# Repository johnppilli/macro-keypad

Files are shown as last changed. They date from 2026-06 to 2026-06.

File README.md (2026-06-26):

# Macro Keypad — Custom USB Mechanical Keypad (KiCad)

A custom 9-key (3×3) USB-C mechanical macro keypad, designed from schematic to
fabrication in KiCad around an **RP2040** microcontroller. This is my own design —
schematic capture, component selection, PCB layout, and fabrication.

## The fabricated board

| Top | Bottom |
| --- | --- |
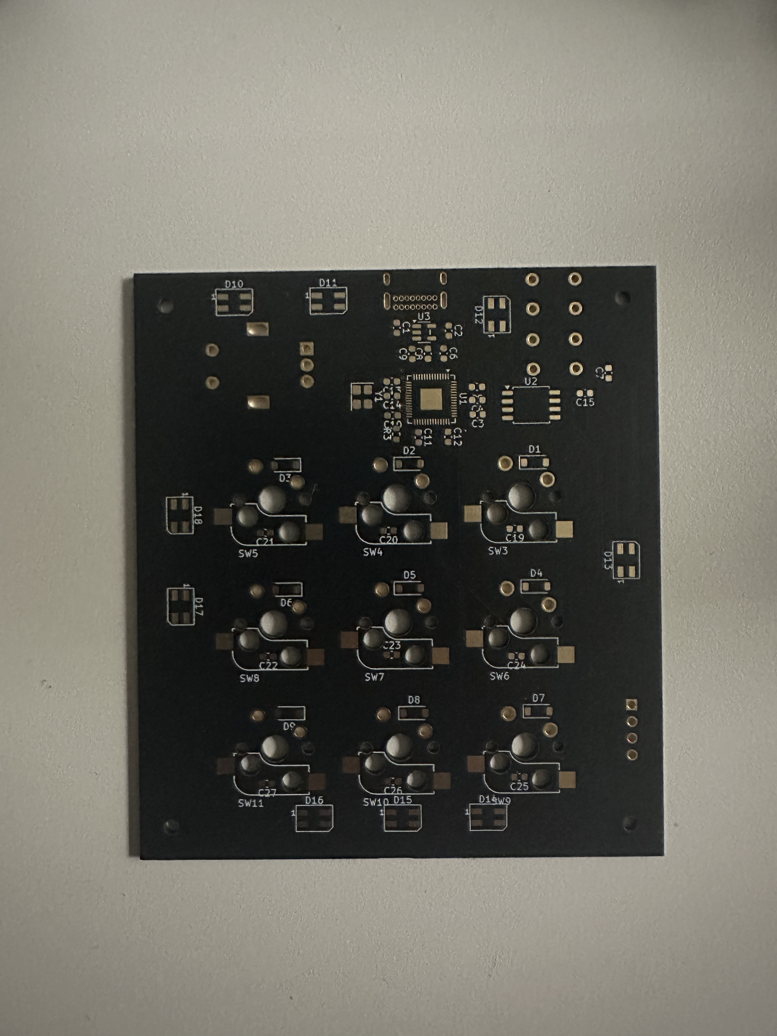
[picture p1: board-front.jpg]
Board top
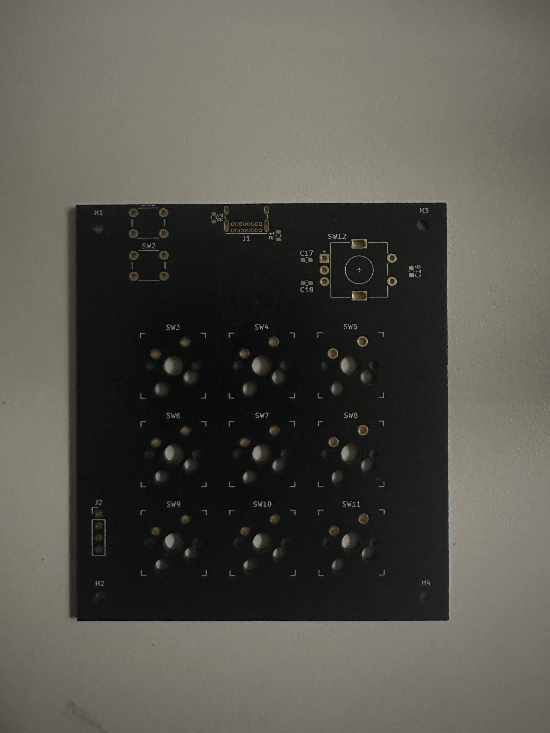
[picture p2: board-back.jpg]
Board bottom
|  |  |

*Bare 2-layer board from JLCPCB, prior to switch/component assembly.*

## Design highlights

- **RP2040** microcontroller with USB-C for both power and data
- **USBLC6** ESD protection on the USB data lines
- **3×3 matrix of 9 mechanical key switches**, each with a per-key diode for N-key
  rollover / anti-ghosting during matrix scanning
- Decoupling on each supply pin; crystal and supporting passives per the RP2040
  reference design
- **2-layer PCB**, board outline defined in Edge.Cuts, ERC/DRC clean
- Gerbers + drill files generated and **fabricated through JLCPCB**

## What's in this repo

- `macro-keypad.kicad_sch` / `.kicad_pcb` / `.kicad_pro` — the KiCad project
- `macro-keypad.pdf` — schematic PDF
- `gerbers/` — fabrication outputs
- `board-front.jpg` / `board-back.jpg` — photos of the fabricated board

## Status — in progress

Bare fabricated board is in hand. Currently:

- **Hand-soldering** the switches, per-key diodes, and supporting components onto the board
- **Writing the RP2040 firmware** — USB-HID keyboard with matrix scanning and debounce

Next up: bring-up and testing once assembly is complete.

## Tools

KiCad · JLCPCB

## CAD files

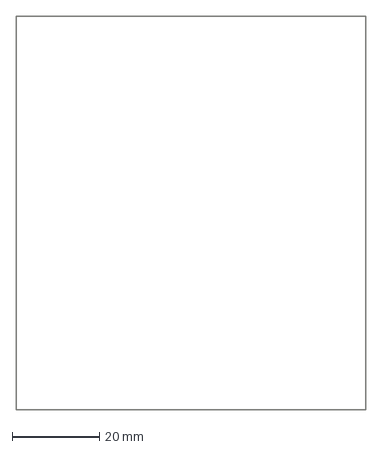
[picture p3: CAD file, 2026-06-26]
macro-keypad-Edge_Cuts.dxf
80.1 x 90.0 mm

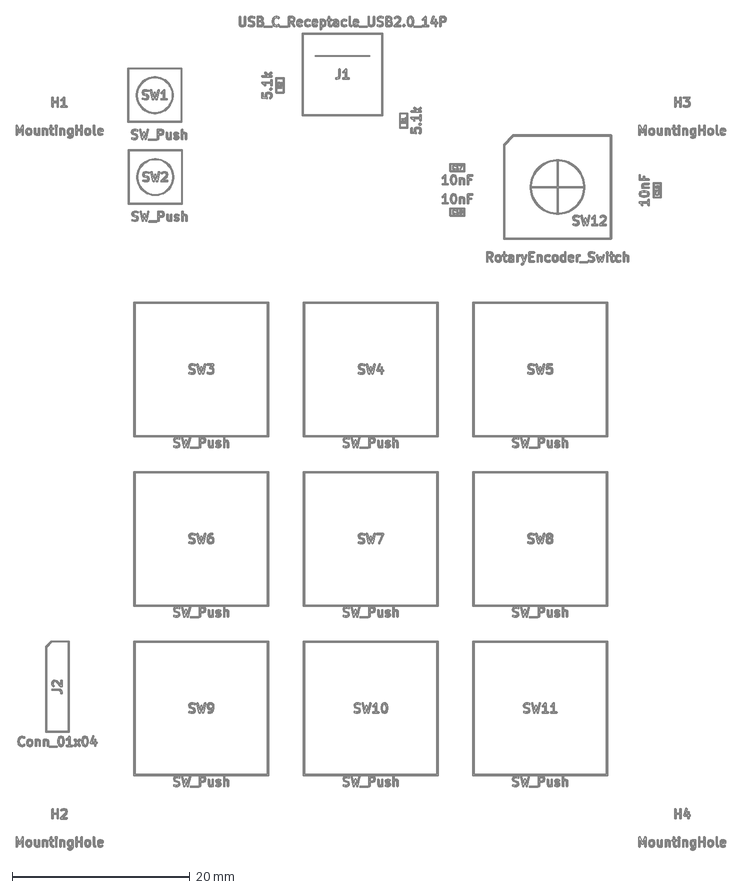
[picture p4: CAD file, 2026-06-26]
macro-keypad-F_Fab.dxf
79.8 x 93.7 mm

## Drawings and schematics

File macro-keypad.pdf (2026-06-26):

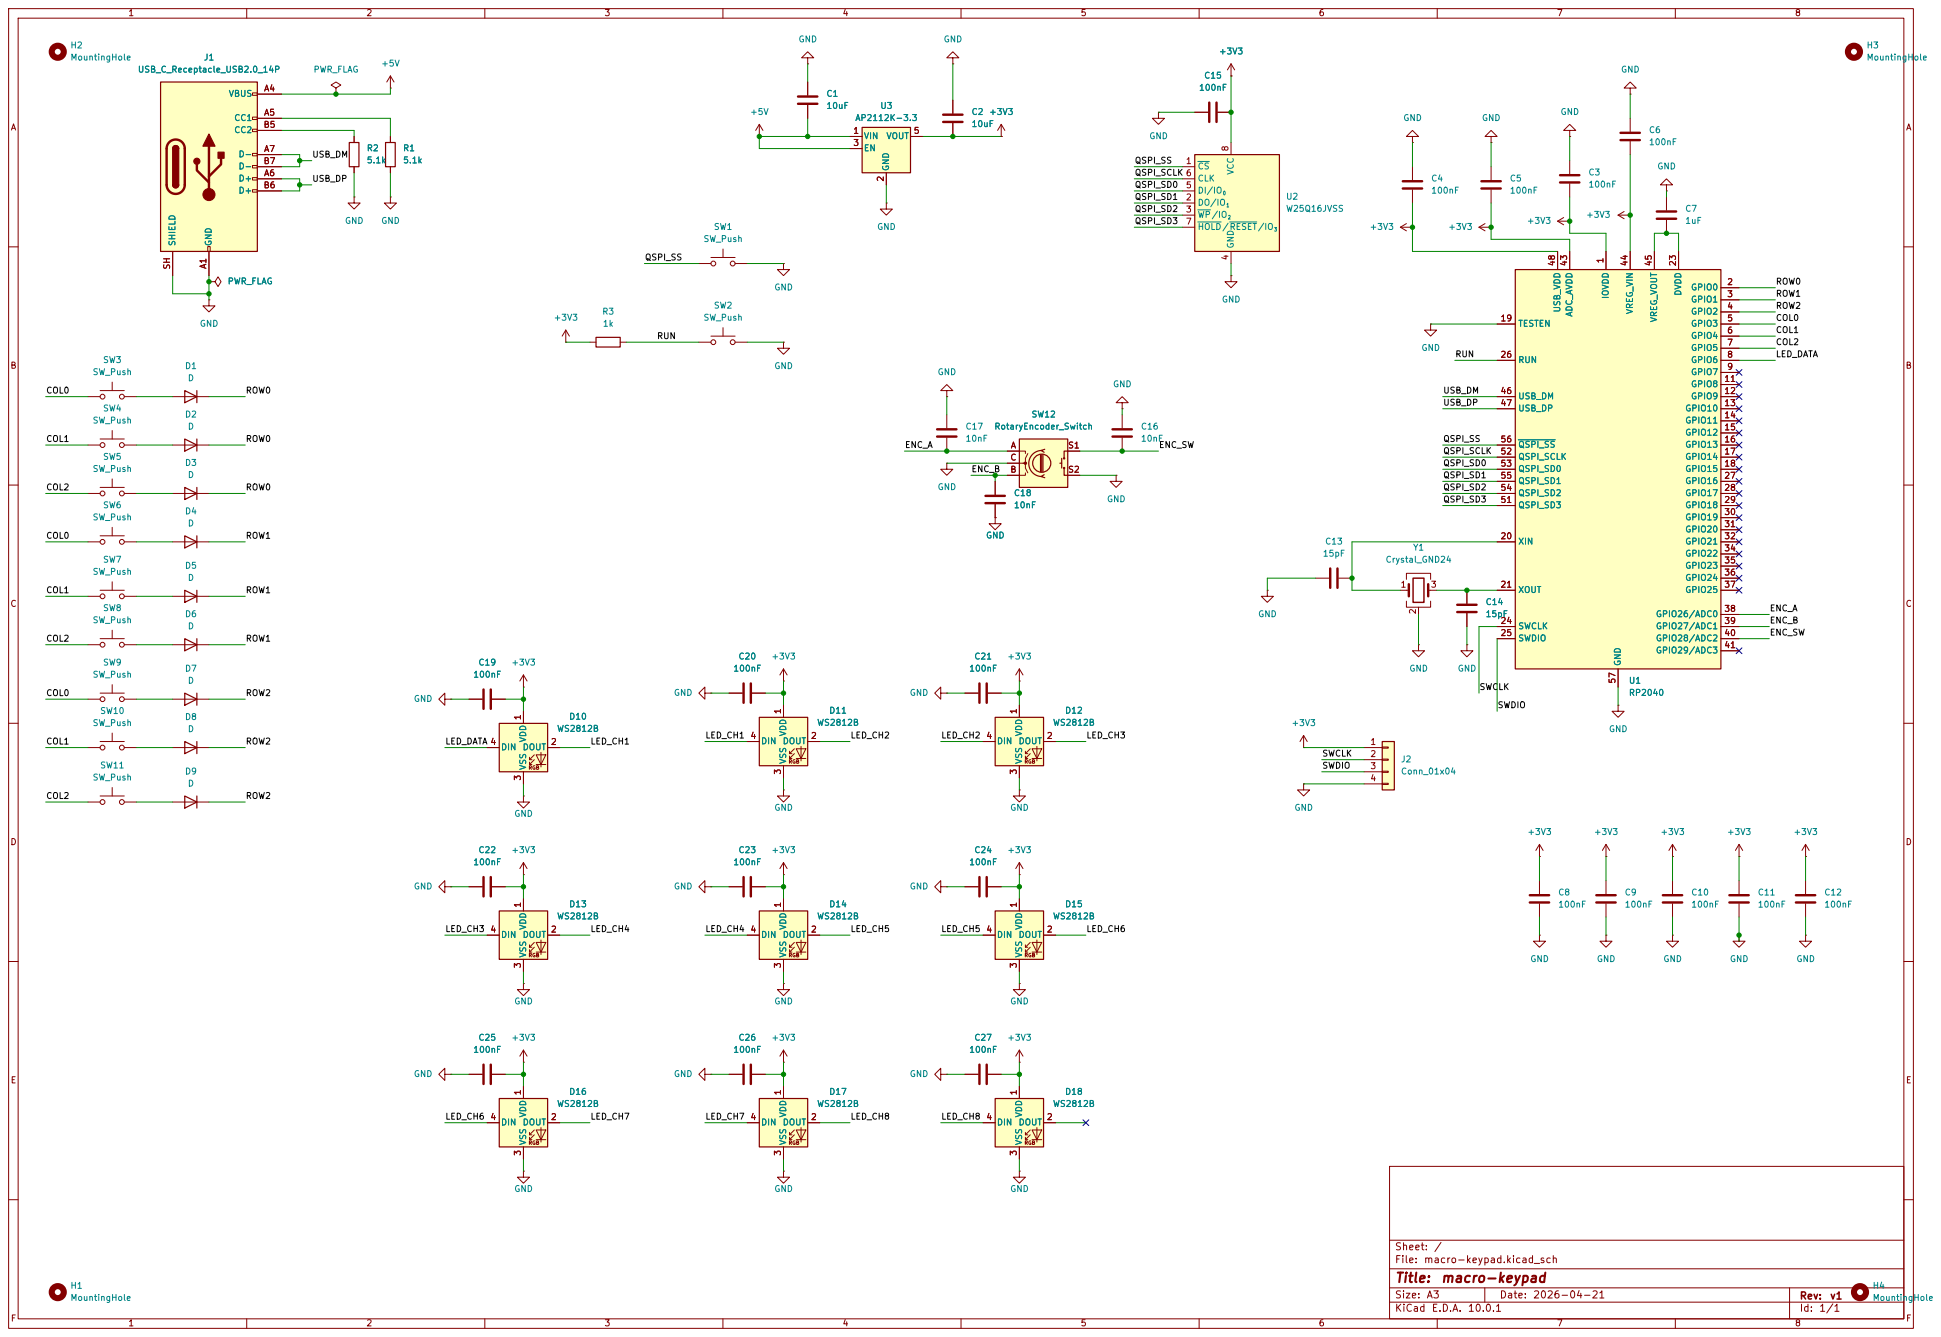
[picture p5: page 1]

4 DI/IO0 5 CLK 6 HOLD/RESET/IO3 7 VCC

Size: A3 | Rev: v1 | F Date: 2026-04-21
KiCad E.D.A. 10.0.1 | Id: 1/1

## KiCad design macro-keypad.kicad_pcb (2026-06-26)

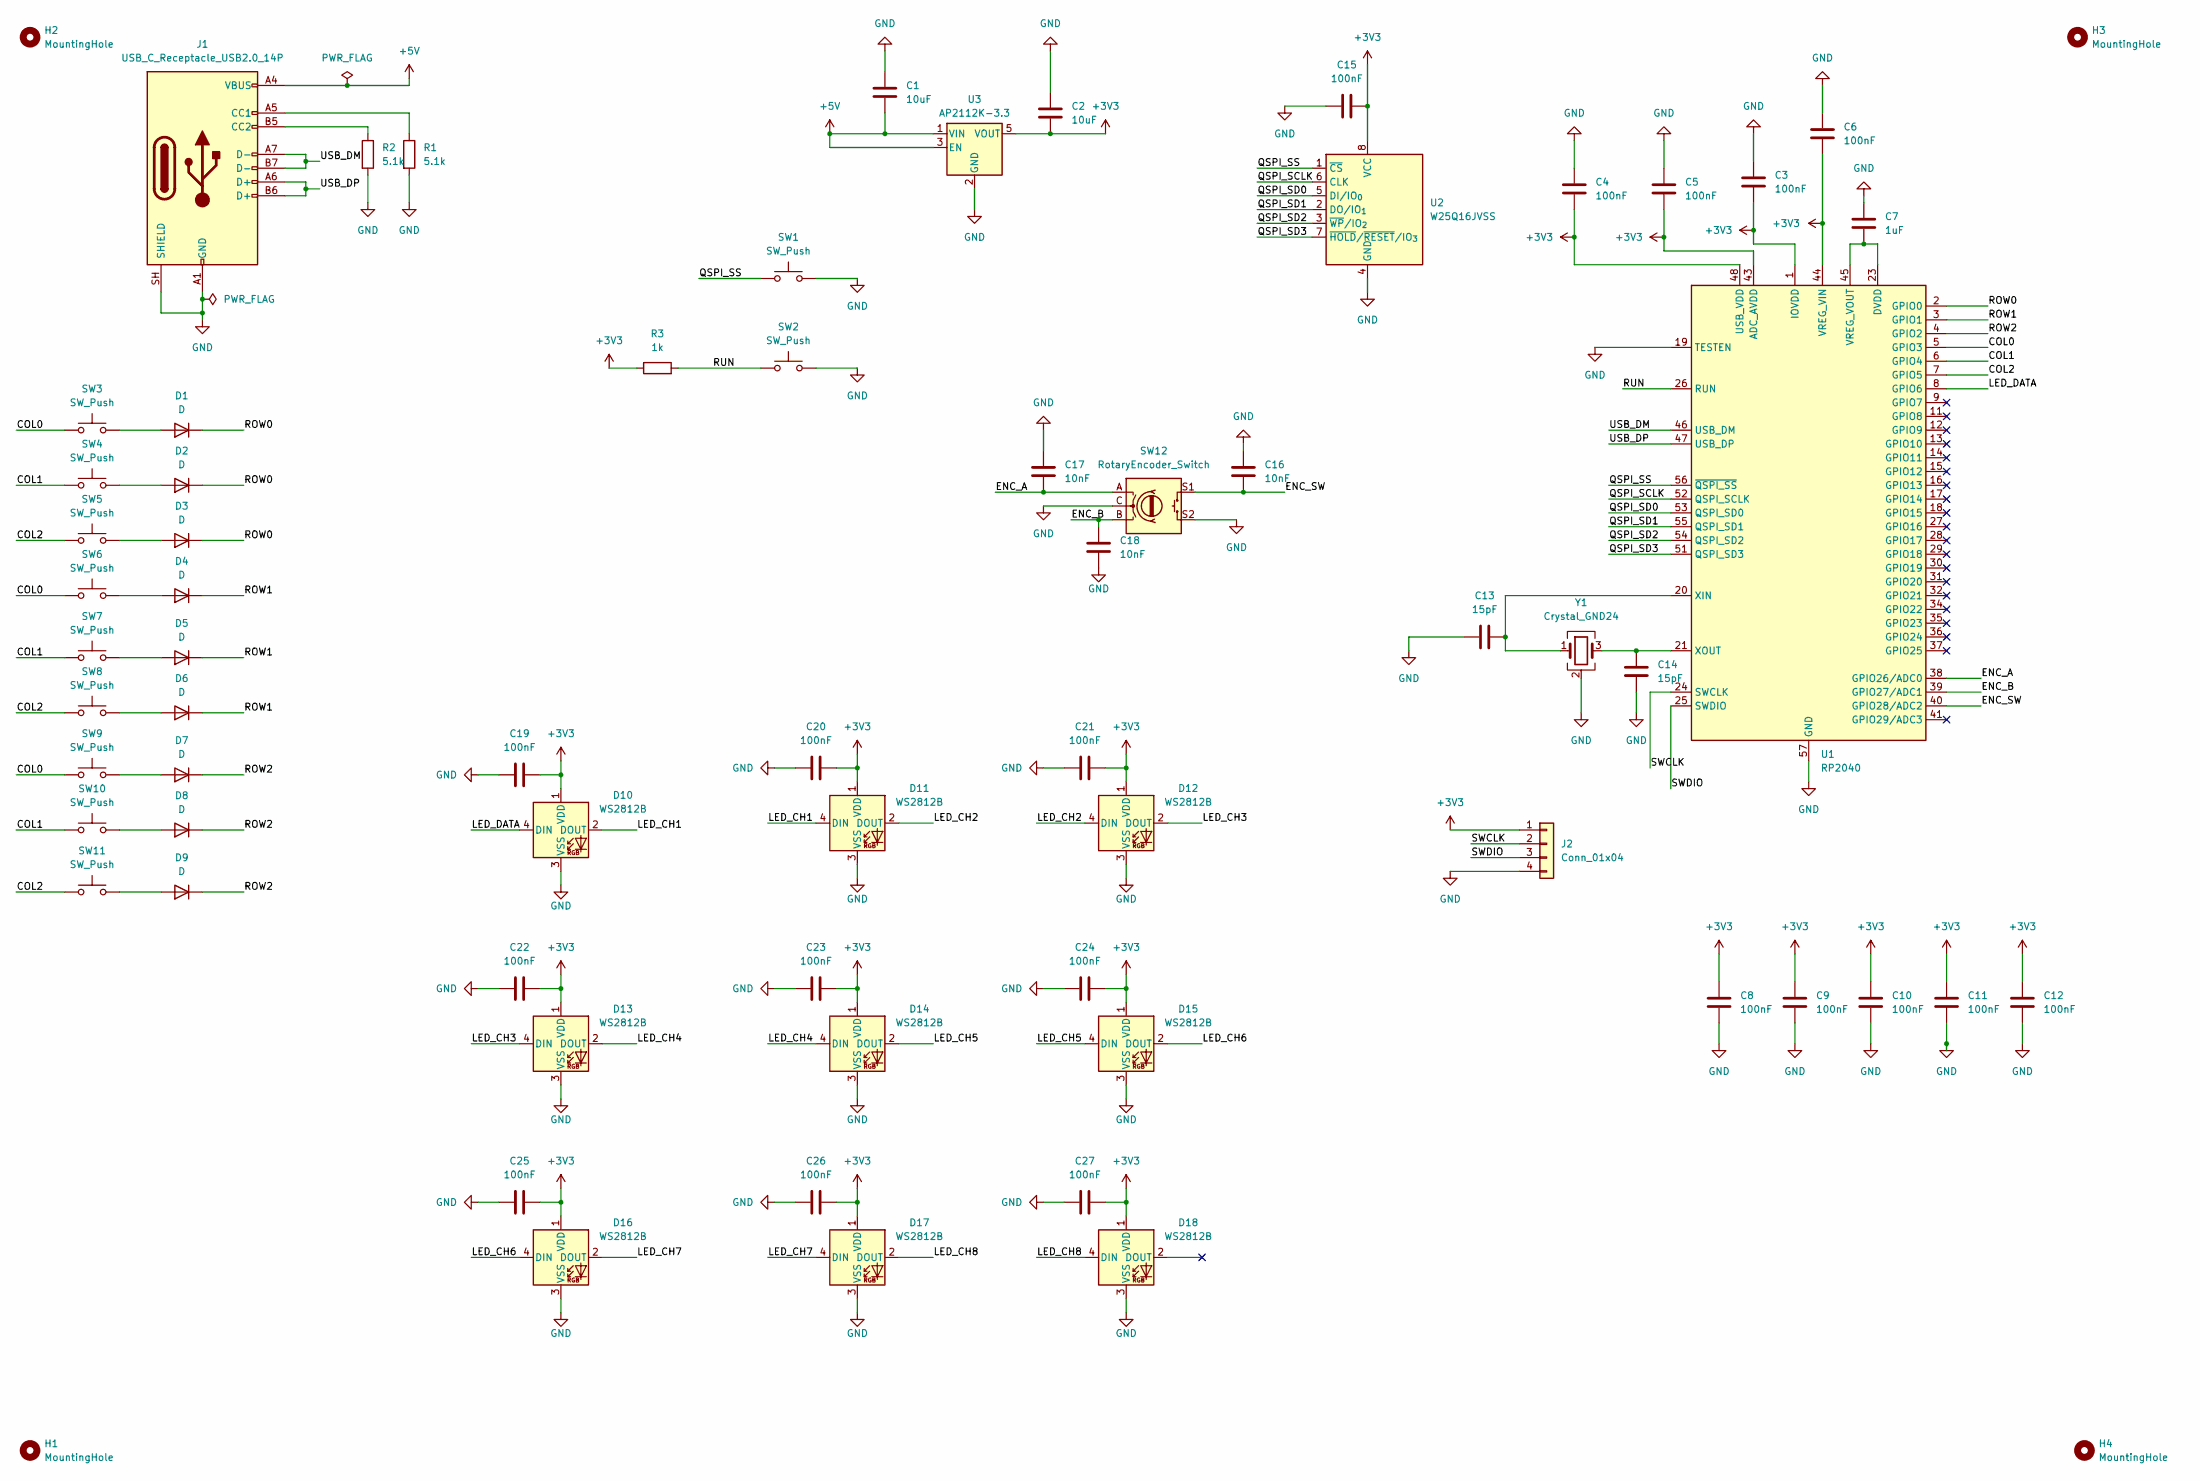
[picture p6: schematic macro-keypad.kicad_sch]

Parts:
C1, C2: 10uF; C_0603_1608Metric
C3, C4, C5, C6, C8, C9, C10, C11, C12, C15, C19, C20, C21, C22, C23, C24, C25, C26, C27: 100nF; C_0603_1608Metric
C7: 1uF; C_0603_1608Metric
C13, C14: 15pF; C_0603_1608Metric
C16, C17, C18: 10nF; C_0603_1608Metric
D1, D2, D3, D4, D5, D6, D7, D8, D9: D; D_SOD-123
D10, D11, D12, D13, D14, D15, D16, D17, D18: WS2812B; LED_WS2812B_PLCC4_5.0x5.0mm_P3.2mm
H1, H2, H3, H4: MountingHole; MountingHole_2.2mm_M2
J1: USB_C_Receptacle_USB2.0_14P; USB_C_Receptacle_GCT_USB4085
J2: Conn_01x04; PinHeader_1x04_P2.54mm_Vertical
R1, R2: 5.1k; R_0603_1608Metric
R3: 1k; R_0603_1608Metric
SW1, SW2: SW_Push; SW_PUSH_6mm
SW3, SW4, SW5, SW6, SW7, SW8, SW9, SW10, SW11: SW_Push; Kailh_socket_MX_optional
SW12: RotaryEncoder_Switch; RotaryEncoder_Alps_EC11E-Switch_Vertical_H20mm
U1: RP2040; QFN-56-1EP_7x7mm_P0.4mm_EP3.2x3.2mm
U2: W25Q16JVSS; SOIC-8_5.3x5.3mm_P1.27mm
U3: AP2112K-3.3; SOT-23-5
Y1: Crystal_GND24; Crystal_SMD_3225-4Pin_3.2x2.5mm

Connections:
+3V3: C2.1, C3.2, C4.2, C5.2, C6.2, C8.1, C9.1, C10.1, C11.1, C12.1, C15.2, C19.2, C20.2, C21.2, C22.2, C23.2, C24.2, C25.2, C26.2, C27.2, D10.1 (VDD), D11.1 (VDD), D12.1 (VDD), D13.1 (VDD), D14.1 (VDD), D15.1 (VDD), D16.1 (VDD), D17.1 (VDD), D18.1 (VDD), J2.1, R3.1, U1.1 (IOVDD), U1.10 (IOVDD), U1.22 (IOVDD), U1.33 (IOVDD), U1.42 (IOVDD), U1.43 (ADC_AVDD), U1.44 (VREG_VIN), U1.48 (USB_VDD), U1.49 (IOVDD), U2.8 (VCC), U3.5 (VOUT)
+5V: C1.2, J1.A4 (VBUS), J1.A9 (VBUS), J1.B4 (VBUS), J1.B9 (VBUS), U3.1 (VIN), U3.3 (EN)
/COL0: SW3.1, SW6.1, SW9.1, U1.5 (GPIO3)
/COL1: SW4.1, SW7.1, SW10.1, U1.6 (GPIO4)
/COL2: SW5.1, SW8.1, SW11.1, U1.7 (GPIO5)
/ENC_A: C17.2, SW12.A, U1.38 (GPIO26/ADC0)
/ENC_B: C18.1, SW12.B, U1.39 (GPIO27/ADC1)
/ENC_SW: C16.2, SW12.S1, U1.40 (GPIO28/ADC2)
/LED_CH1: D10.2 (DOUT), D11.4 (DIN)
/LED_CH2: D11.2 (DOUT), D12.4 (DIN)
/LED_CH3: D12.2 (DOUT), D13.4 (DIN)
/LED_CH4: D13.2 (DOUT), D14.4 (DIN)
/LED_CH5: D14.2 (DOUT), D15.4 (DIN)
/LED_CH6: D15.2 (DOUT), D16.4 (DIN)
/LED_CH7: D16.2 (DOUT), D17.4 (DIN)
/LED_CH8: D17.2 (DOUT), D18.4 (DIN)
/LED_DATA: D10.4 (DIN), U1.8 (GPIO6)
/QSPI_SCLK: U1.52 (QSPI_SCLK), U2.6 (CLK)
/QSPI_SD0: U1.53 (QSPI_SD0), U2.5 (DI/IO_{0})
/QSPI_SD1: U1.55 (QSPI_SD1), U2.2 (DO/IO_{1})
/QSPI_SD2: U1.54 (QSPI_SD2), U2.3 (~WP/IO_{2})
/QSPI_SD3: U1.51 (QSPI_SD3), U2.7 (~HOLD/~RESET/IO_{3})
/QSPI_SS: SW1.1, U1.56 (~QSPI_SS), U2.1 (~CS)
/ROW0: D1.1 (K), D2.1 (K), D3.1 (K), U1.2 (GPIO0)
/ROW1: D4.1 (K), D5.1 (K), D6.1 (K), U1.3 (GPIO1)
/ROW2: D7.1 (K), D8.1 (K), D9.1 (K), U1.4 (GPIO2)
/RUN: R3.2, SW2.1, U1.26 (RUN)
/SWCLK: J2.2, U1.24 (SWCLK)
/SWDIO: J2.3, U1.25 (SWDIO)
/USB_DM: J1.A7 (D-), J1.B7 (D-), U1.46 (USB_DM)
/USB_DP: J1.A6 (D+), J1.B6 (D+), U1.47 (USB_DP)
GND: C1.1, C2.2, C3.1, C4.1, C5.1, C6.1, C7.1, C8.2, C9.2, C10.2, C11.2, C12.2, C13.2, C14.2, C15.1, C16.1, C17.1, C18.2, C19.1, C20.1, C21.1, C22.1, C23.1, C24.1, C25.1, C26.1, C27.1, D10.3 (VSS), D11.3 (VSS), D12.3 (VSS), D13.3 (VSS), D14.3 (VSS), D15.3 (VSS), D16.3 (VSS), D17.3 (VSS), D18.3 (VSS), J1.A1 (GND), J1.A12 (GND), J1.B1 (GND), J1.B12 (GND), J1.SH (SHIELD), J2.4, R1.2, R2.2, SW1.2, SW2.2, SW12.C, SW12.S2, U1.19 (TESTEN), U1.57 (GND), U2.4 (GND), U3.2 (GND), Y1.2 (G), Y1.4 (G)
unnamed: D1.2 (A), SW3.2
unnamed: D2.2 (A), SW4.2
unnamed: D3.2 (A), SW5.2
unnamed: D4.2 (A), SW6.2
unnamed: D5.2 (A), SW7.2
unnamed: D6.2 (A), SW8.2
unnamed: D7.2 (A), SW9.2
unnamed: D8.2 (A), SW10.2
unnamed: D9.2 (A), SW11.2
unnamed: J1.A5 (CC1), R1.1
unnamed: J1.B5 (CC2), R2.1
unnamed: C7.2, U1.23 (DVDD), U1.45 (VREG_VOUT), U1.50 (DVDD)
unnamed: C13.1, U1.20 (XIN), Y1.1
unnamed: C14.1, U1.21 (XOUT), Y1.3

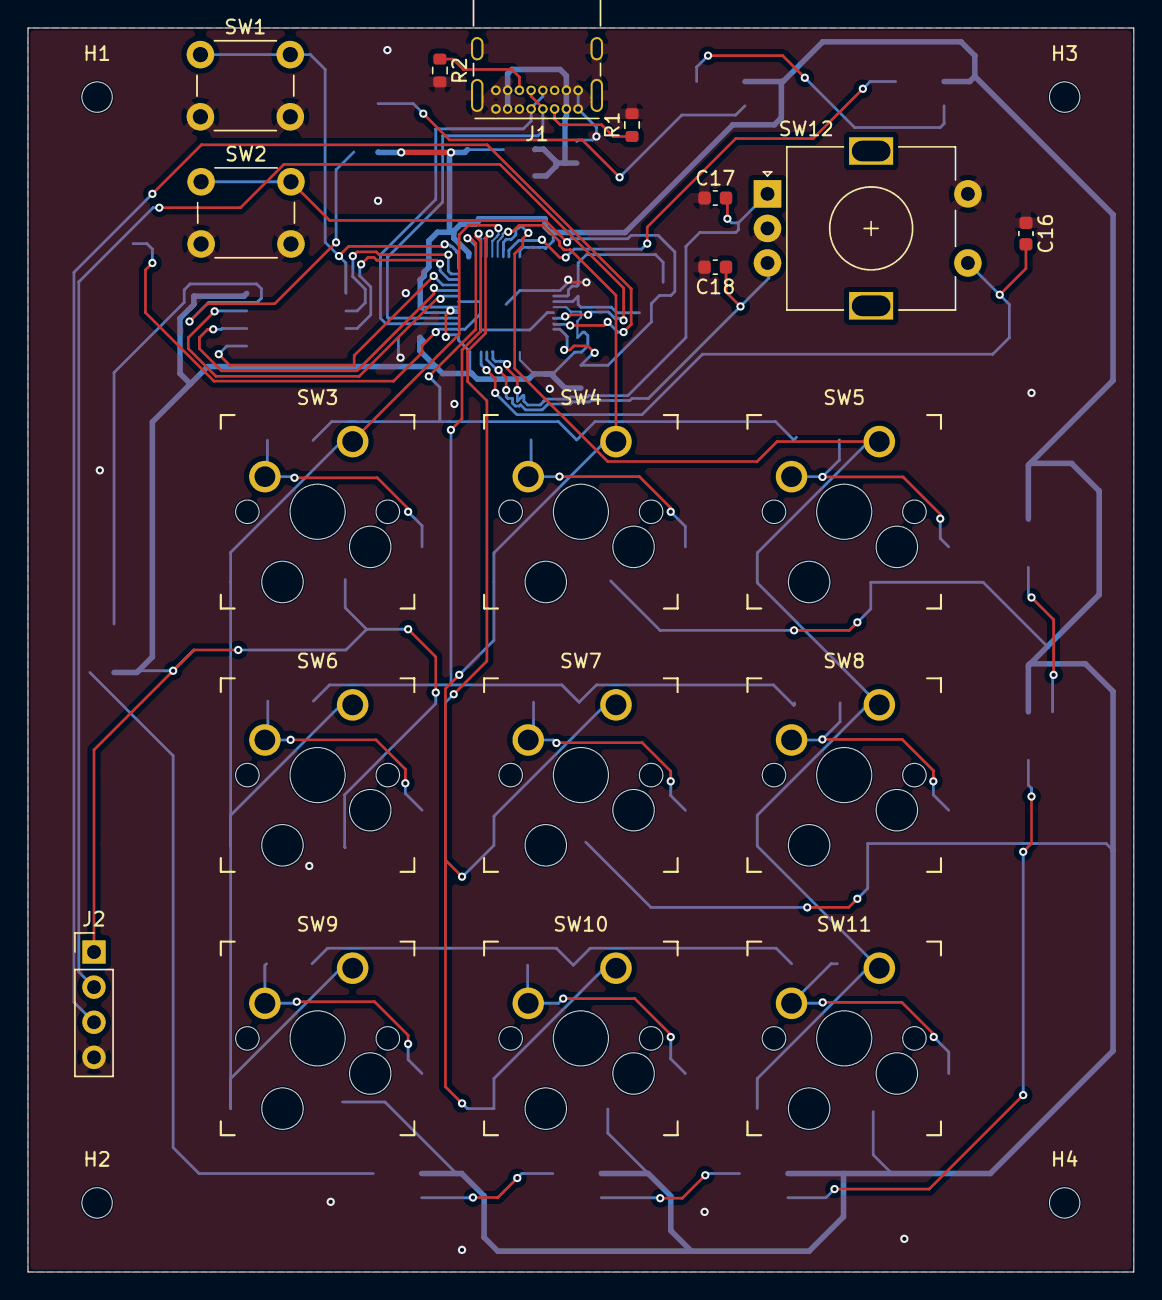
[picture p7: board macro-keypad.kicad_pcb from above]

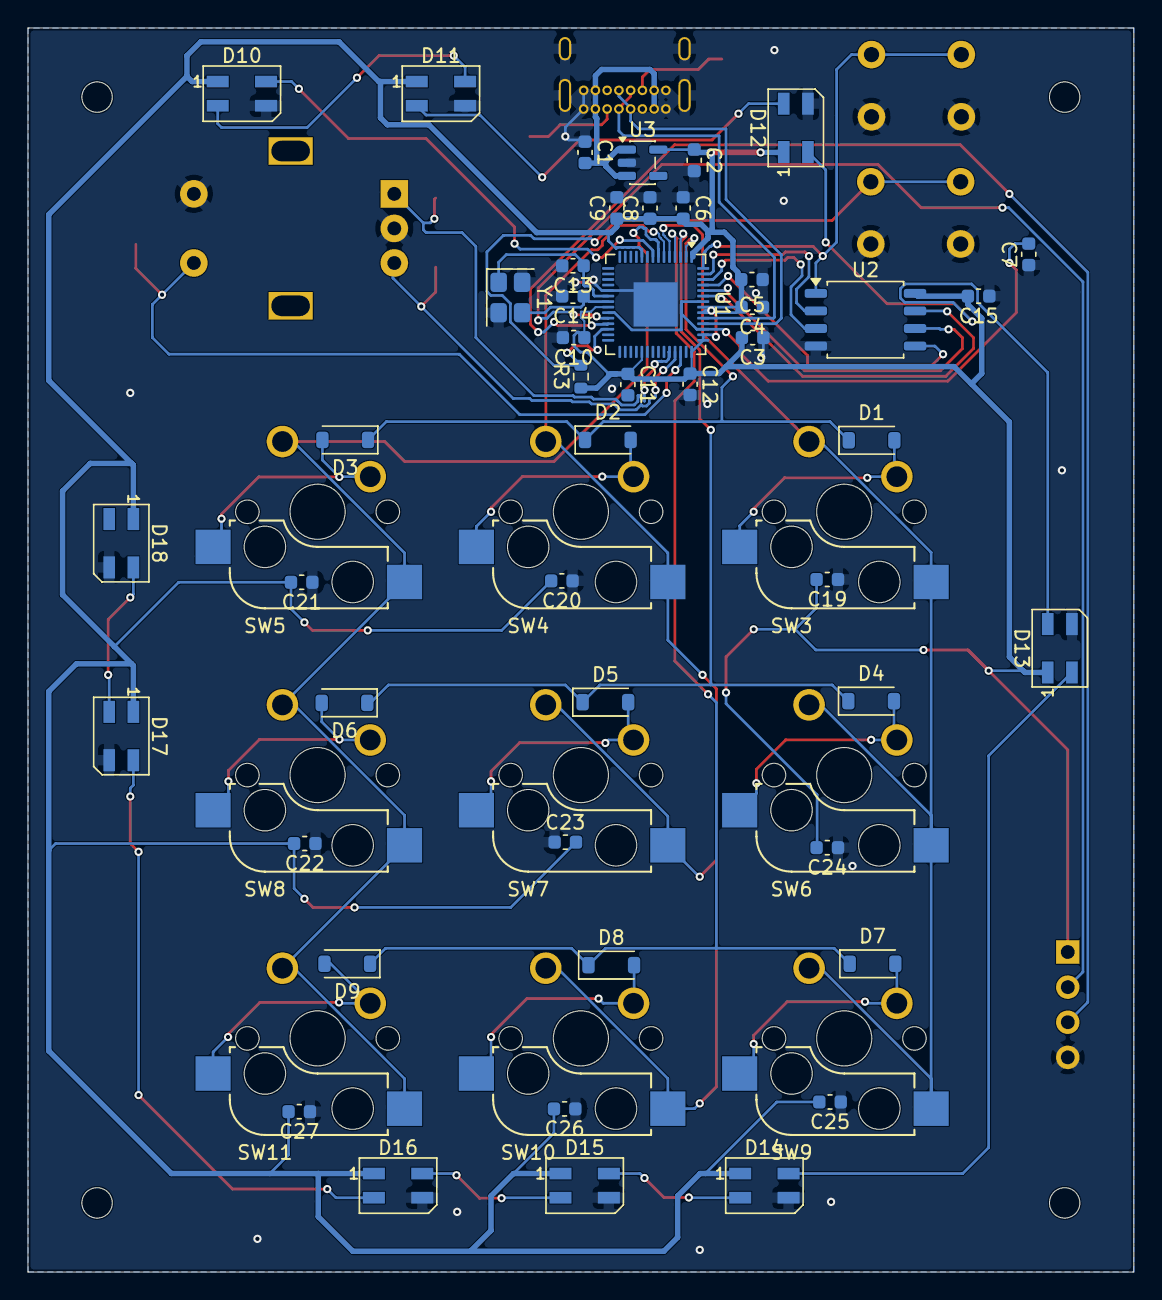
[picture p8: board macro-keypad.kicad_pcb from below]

Board: 2 copper layers, 80.0 x 90.0 mm, 70 parts (47 on the bottom side), 46 nets.

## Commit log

2026-06-26 Custom USB macro keypad - KiCad design + fabriated board
    [macro-keypad-Edge_Cuts.dxf, macro-keypad-F_Fab.dxf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]
2026-06-26 Add current status - assembly and firmware in progress
